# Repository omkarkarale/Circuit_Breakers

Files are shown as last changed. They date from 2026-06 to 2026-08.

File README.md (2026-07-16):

<h1 align="center">⚡ Circuit Breakers</h1>
<h3 align="center">MakerMania 2026 — Innovation Project Workbook</h3>

<p align="center">
  
  
  
</p>

<div align="center">

### 🛠️ Technologies Used





[]()

</div>

<p align="center">
  <strong>Program Duration:</strong> 1 June 2026 – 4 July 2026 &nbsp;·&nbsp;
  <strong>Location:</strong> MBF Tinkerers' Lab 007 &nbsp;·&nbsp;
  <strong>Team Size:</strong> 3 Students
</p>

<p align="center">
  <em>Identify a real-world problem and develop an innovative, patentable, and implementable solution.</em>
</p>

<p align="center">
  <a href="https://youtu.be/VeL1t_9wYrM?si=e5plWxUvcQX88zFm"><strong>📺 Advertisement Video</strong></a>
  &nbsp;&nbsp;|&nbsp;&nbsp;
  <a href="https://canva.link/8ibtr7vefrchxkn"><strong>📊 SCAMPER Presentation</strong></a>
</p>

---

# 1. Team Identity

## 1.1 Team Name and Photo

Team Name: Circuit Breakers

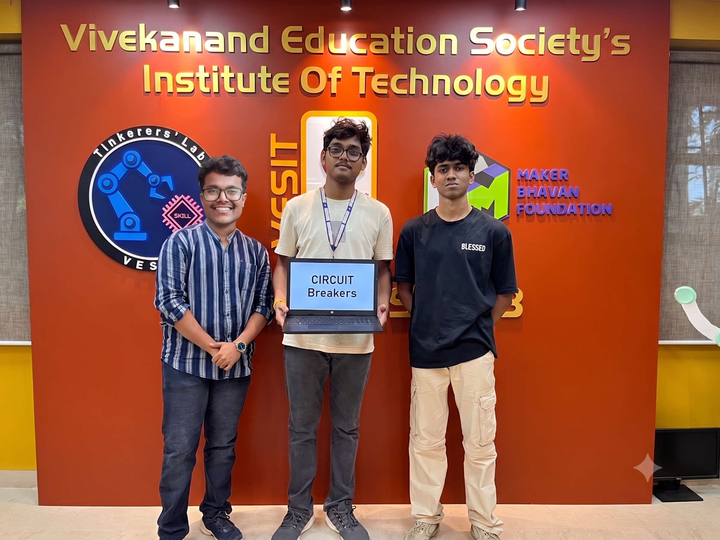
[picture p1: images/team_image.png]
<br>
---

## 1.2 Team Members

| Name | Role | Skills |
| ---- | ---- | --- |
| Rajnarayan Hazra | Hardware & Testing Lead | Arduino Mega programming, serial communication, documentation, electronics assembly |
| Omkar Karale | Software & IoT Lead | ESP8266 programming, app integration, 3D CAD |
| Ekansh Bansode | Mechanical Lead | 3D printing |

---

# 2. Problem Discovery

## 2.1 Observation Area

Where did you conduct your observations?

* Hostel
* Canteen
* Workshop
* **Hospital** (selected)
* Public Transport
* **Home** (selected)
* **Other** — Elderly care and caregiver support (selected)

---

## 2.2 AEIOU Observation Sheet

### Activities

What are users doing?

Users need to take different medicines at fixed times throughout the day (Medicine Scheduling), identify the correct medicine compartment and dosage (Dose Identification via LCD and voice guidance), and retrieve the correct medicine as the device rotates the compartment housing into position using the 28BYJ-48 stepper + ULN2003 (Medicine Retrieval).

### Environment

What conditions affect them?

The device is intended for homes, bedside tables, clinics, and elderly care spaces. Users may face forgetfulness, low vision, difficulty reading labels, or confusion when multiple medicines look similar.

### Interactions

Who or what are they interacting with?

The user interacts with the LCD display, voice announcements, the rotating medicine compartments, and the IR sensor. The companion app connects to the device over Wi-Fi through the ESP8266, which relays commands to the Arduino Mega over a serial connection; the Mega drives the hardware (motor, display, audio, sensor) while the ESP8266 handles logging and storage. Caregivers can use this app connectivity for schedule setup and notifications.

### Objects

What tools or products are used?

ESP8266 DevKit, DS3231 RTC, 16x2 LCD, 28BYJ-48 stepper motor + ULN2003 driver, DFPlayer Mini + speaker, IR sensor, Arduino Mega, and a custom 3D-printed (PLA) medicine compartment housing.

### Users

Who are the primary users?

The primary users are elderly patients and people with complex medication schedules. Secondary users include caregivers, family members, and healthcare workers.

---

## 2.3 Observation Log

| Observation | Evidence | Pain Point |
| --- | --- | --- |
| Elderly users may forget medicine timings. | Daily medicine routines often depend on alarms, handwritten notes, or caregiver reminders. | Missed doses reduce treatment effectiveness. |
| Multiple medicines can create confusion. | Similar tablets or unclear compartments make selection difficult. | Users may take the wrong medicine or dosage. |
| Caregivers cannot always monitor intake in person. | Family members may be away during scheduled medicine times. | No reliable confirmation that medicine was accessed. |

---

# 3. User Research

## 3.1 Interview Summary

Number of users interviewed: **Elderly users, family members, and caregivers**

Methods used: Informal interviews, observation, and discussion of daily medicine routines.

## 3.2 Key Quotes

1. "A normal alarm tells the time, but it does not tell which medicine to take."

2. "It is difficult to remember tablets when there are many doses in one day."

3. "Caregivers need to know whether the medicine was actually accessed."

---

## 3.3 User Persona

### Name

Mr. Das

### Age

68 years

### Occupation

Retired

### Goals

Take medicines on time, avoid confusion, and remain independent.

### Frustrations

Forgetting doses, reading small labels, and depending on family members.

### Needs

Clear reminders, voice guidance, visible compartment indication, and simple operation.

---

# 4. Problem Framing

## Problem Statement

User **elderly patients and people with complex medication schedules** needs a way to **identify and take the correct medicine at the correct time** because **missed doses, wrong doses, and dependency on caregivers can affect health and independence**.

---

## How Might We Questions

1. How might we help elderly users identify the correct medicine without confusion?

2. How might we make medicine reminders clearer than a normal phone alarm?

3. How might we help caregivers receive confirmation of medicine access?

---

## Opportunity Ranking

| Criteria | Score |
| --- | ----- |
| Severity | 5 — Incorrect or missed medication can directly affect health. |
| Frequency | 5 — Medicines are often taken daily and multiple times per day. |
| Feasibility | 4 — Uses affordable and commonly available components. |
| Novelty | 4 — Combines a custom 3D-printed compartment design, voice guidance, motorized positioning, and IoT. |
| Market Potential | 4 — Useful for elderly care, home healthcare, and caregiver support. |
| Total | 22/25 |

---

# 5. Solution Ideation

## Brainstormed Ideas

| Idea | Advantages | Challenges |
| ---- | --- | --- |
| Mobile medicine reminder app | Easy to update schedules and send notifications | Does not physically guide medicine selection |
| Alarm-based pill box | Simple and low cost | User still needs to open the correct compartment |
| Smart rotating medicine organizer | Provides reminder, sorting, voice guidance, visual indication, and access detection | Requires motor calibration and reliable mechanical alignment |

---

## Selected Concept

Why was this concept chosen?

The selected concept is a Smart Medicine Sorting and Reminder Device built using a custom 3D-printed (PLA) compartment housing, designed by taking inspiration from existing web references rather than reusing an off-the-shelf part. It solves both the reminder and medicine identification problems by alerting the user, rotating to the correct compartment, providing voice instructions, and detecting compartment access.

---

# 6. System Design

## High-Level Description

Explain your solution.

The Smart Medicine Sorting and Reminder Device is an IoT-enabled healthcare solution that helps elderly patients and individuals with complex medication schedules take medicines on time and correctly. Medicines are preloaded into weekly compartments inside a custom 3D-printed (PLA) housing. The system runs on two controllers working together: the **Arduino Mega** drives all hardware — reading the DS3231 RTC, updating the 16x2 LCD, playing voice reminders through the DFPlayer Mini and speaker, rotating the 28BYJ-48 stepper motors to the correct compartment, and reading the IR sensor — while the **ESP8266** connects over Wi-Fi to the companion app, sends commands to the Mega over a serial link, and handles log storage. At the correct time, the device announces the reminder, shows medicine information on the LCD, and rotates to the correct slot; the IR sensor detects access and supports logging or caregiver notification. The hardware and software are fully working; current effort is focused on improving the physical enclosure.

---

## Block Diagram

```mermaid
flowchart LR
    A["📱 Mobile App<br/>(Wi-Fi)"]
    B["📡 ESP8266<br/>Wi-Fi + Logging + Storage"]
    C["🔌 Serial (UART)"]
    D["🖥️ Arduino Mega"]

    E["⏰ RTC"]
    F["🖥️ LCD"]
    G["🔊 DFPlayer Mini<br/>+ Speaker"]
    H["⚙️ Stepper Motors"]
    I["📷 IR Sensor"]

    A -->|HTTP API| B
    B -->|UART Serial| C
    C --> D

    D --> E
    D --> F
    D --> G
    D --> H
    D --> I
```
---

## Inputs

List sensors, user inputs, data sources.

* Companion app (via ESP8266 Wi-Fi) — configure schedules and caregiver setup
* DS3231 RTC — accurate real-time scheduling
* IR sensor — detects compartment access or medicine retrieval
* ESP8266 → Arduino Mega (Serial) — relays commands from the app/ESP8266 to the hardware controller

---

## Outputs

List displays, actuators, software outputs.

* 16x2 LCD — shows current time, status, and medication information
* DFPlayer Mini + speaker — voice reminders and dosage instructions
* 28BYJ-48 stepper motors — rotate the compartment housing to the correct slot

---

# 7. Technical Planning

## Electronics

| Component | Purpose |
| --- | --- |
| Arduino Mega | Main hardware controller — drives motors, display, audio, and sensor, and receives commands over serial |
| ESP8266 DevKit | Wi-Fi connectivity, app communication, and log storage |
| DS3231 RTC Module | Accurate real-time clock for medicine schedules |
| 16x2 LCD | Displays time, status, and medicine information |
| 28BYJ-48 Stepper Motor (x3) | Rotates the medicine compartments |
| ULN2003 Motor Driver (x3) | Drives the stepper motors |
| DFPlayer Mini + Speaker | Plays voice reminders and dosage instructions |
| IR Sensor | Detects access or retrieval |
| 12V Adapter / 18650 Battery | Power supply |

---

## Software

| Tool | Purpose |
| ---- | --- |
| Arduino IDE | Firmware development for both ESP8266 and Arduino Mega |
| ESP8266 Arduino Core | ESP8266 programming and wireless features |
| RTC library | DS3231 timekeeping and schedule checking (Mega side) |
| LCD display library | Displaying time, status, and medicine details (Mega side) |
| Stepper motor library | Controlling compartment rotation (Mega side) |
| DFPlayer Mini library | Playing audio reminder files (Mega side) |
| Wi-Fi libraries | Mobile app connectivity and caregiver notifications (ESP8266 side) |
| Serial communication protocol | Passes commands from the ESP8266 to the Arduino Mega |

---

## Mechanical / CAD

Describe fabricated components.

The compartment housing is a custom CAD design, 3D-printed in PLA and built from scratch by taking inspiration from web references — it is not a repurposed 3D-printer filament spool. Multiple sizes and surface finishes were tried across iterations. The housing holds the medicine compartments, motor mounts, and electronics enclosure.

<p align="center">
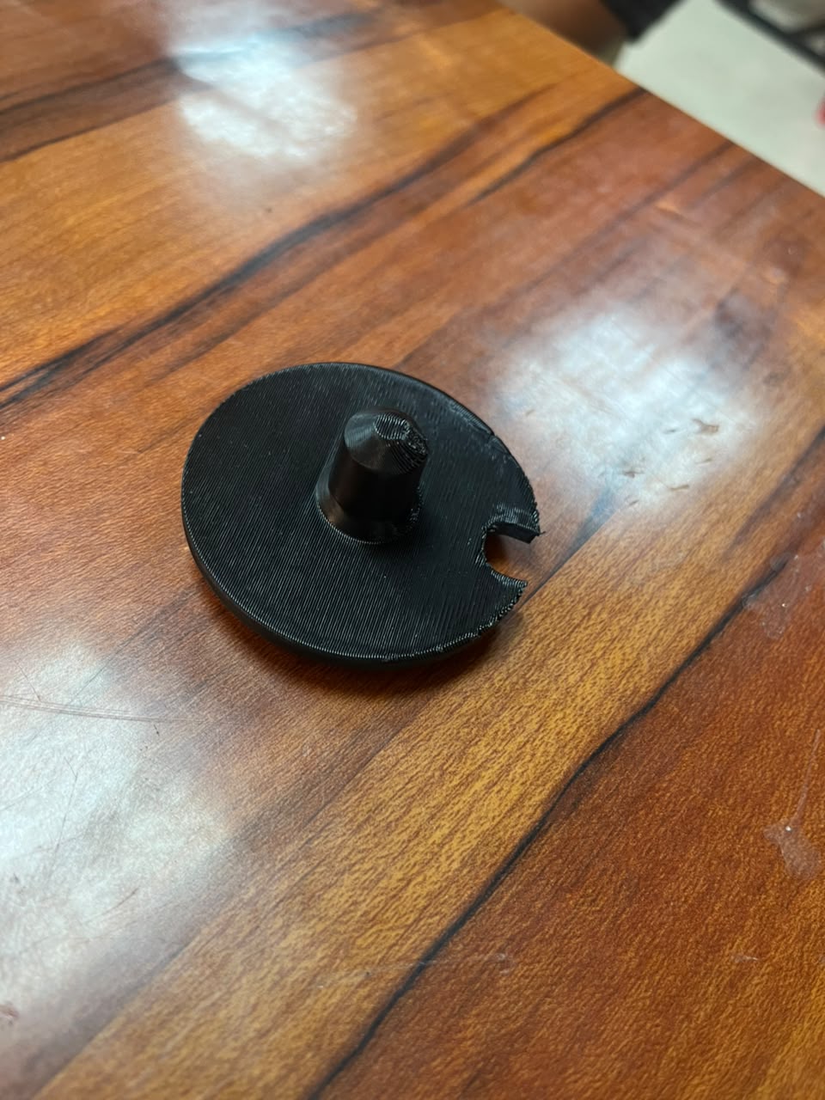
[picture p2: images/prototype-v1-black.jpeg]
Early compartment lid prototype (PLA, black)
  <br>
  <em>Early PLA compartment lid prototype — printed in black filament</em>
</p>

<p align="center">
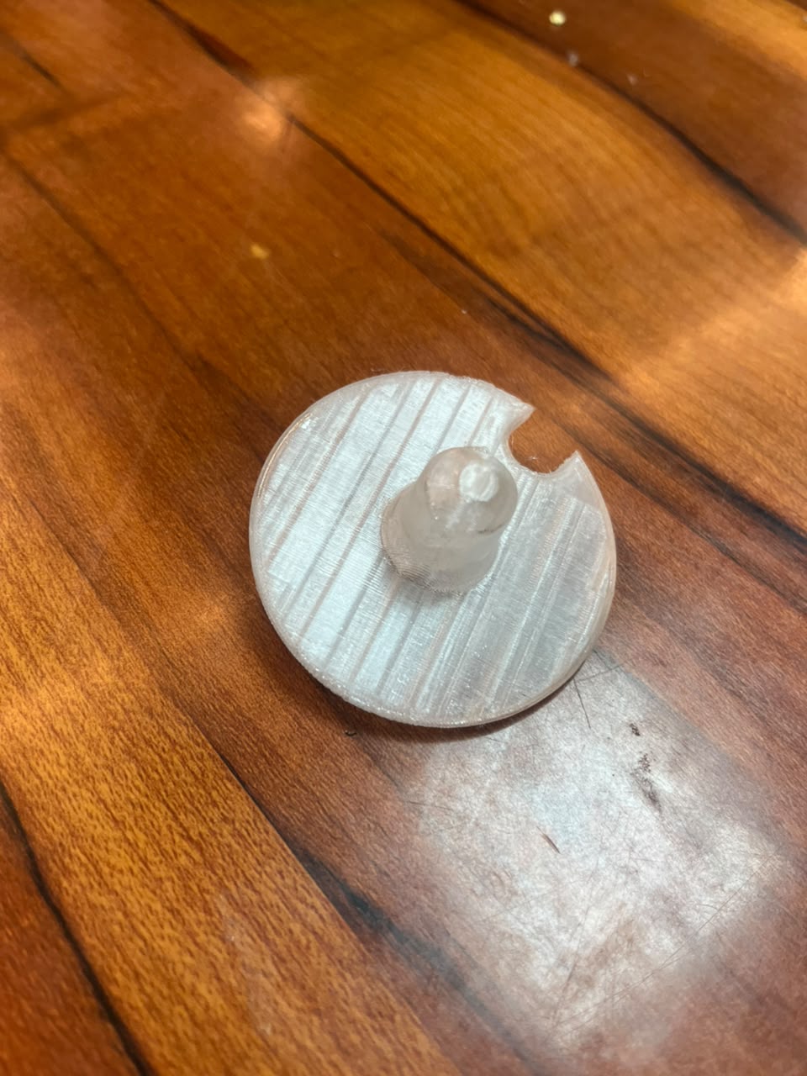
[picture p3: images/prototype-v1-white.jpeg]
Early compartment lid prototype (PLA, white)
  <br>
  <em>Same lid design reprinted in white/translucent PLA to test a different finish</em>
</p>

---

# 8. Prototype Development

## Version 1

Description: Basic circular medicine organizer concept, custom-designed and 3D-printed in PLA (not a recycled filament spool) with marked compartments, inspired by references found online.

Lessons Learned: Compartments must be clearly visible, easy to access, and aligned with the rotation mechanism.

---

## Version 2

Description: Arduino Mega + ESP8266 based prototype with RTC scheduling, LCD display, stepper-based rotation, and serial communication between the two controllers.

Lessons Learned: Accurate timing, motor calibration, and simple feedback are essential for reliable use.

<p align="center">
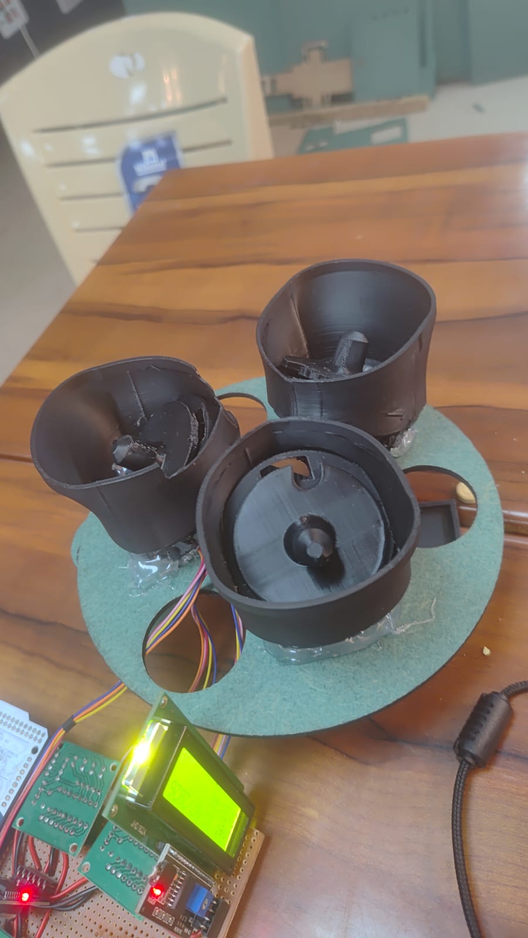
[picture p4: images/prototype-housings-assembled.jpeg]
Three compartment housings assembled on the base
  <br>
  <em>Three 3D-printed compartment housings assembled onto the base with the stepper motors and wiring routed through</em>
</p>

---

## Final Prototype

Description: IoT-enabled medicine sorting and reminder device with voice guidance, motorized compartment positioning, LCD status display, and IR access detection. Hardware (Arduino Mega) and software (ESP8266 + companion app) are fully working and communicate correctly over serial and Wi-Fi.

Current Status: The electronics and firmware are functioning as intended, but the 3D-printed enclosure is not yet finalized. Several iterations were tried — different housing sizes and surface/scrubbing treatments — but the model still has fit, alignment, and durability issues and is not fully user-friendly. Following review feedback from the presentation, further redesign of the physical model is in progress.

<p align="center">
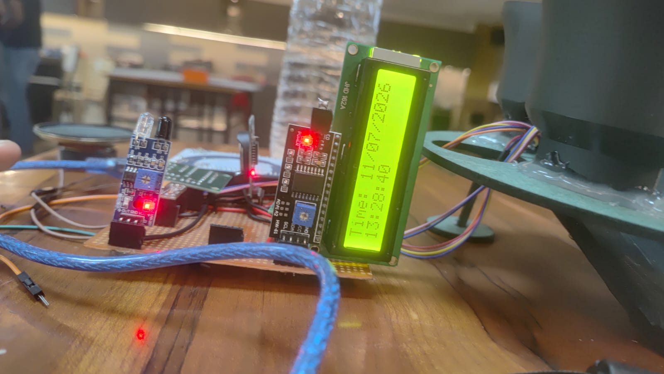
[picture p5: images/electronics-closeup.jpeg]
Close-up of RTC, LCD, and IR sensor wiring
  <br>
  <em>Close-up of the DS3231 RTC, 16x2 LCD, and IR sensor wired on the breadboard</em>
</p>

<p align="center">
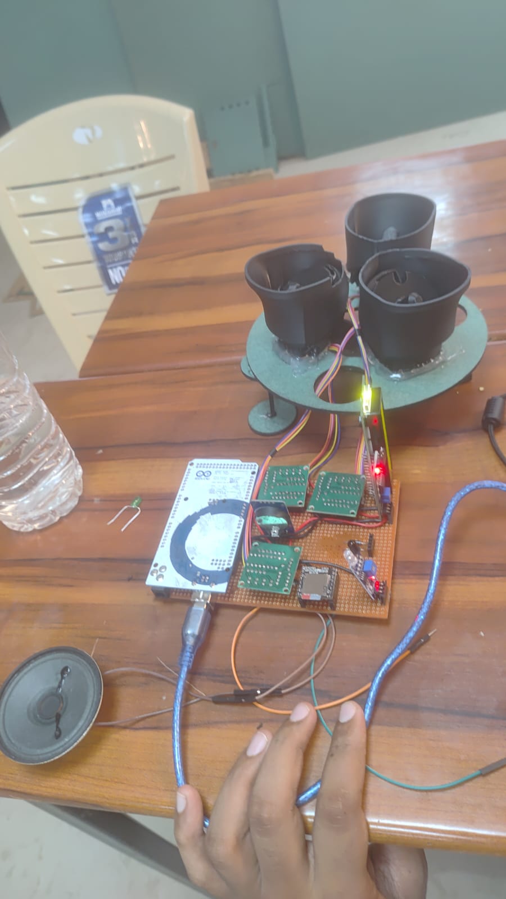
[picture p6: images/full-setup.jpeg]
Full working setup with Arduino Mega, breadboards, and compartment housings
  <br>
  <em>Full working setup — Arduino Mega, breadboard modules, speaker, and compartment housings connected together</em>
</p>

---

# 9. Testing & Validation

## Testing Plan

| Test | Success Criteria |
| ---- | --- |
| RTC schedule reminder | Reminder activates at the programmed time |
| Motor positioning | Compartment housing rotates to the correct slot |
| Voice and sensor feedback | Correct audio plays and access is detected |

---

## User Feedback

| User | Feedback | Action Taken |
| ---- | --- | --- |
| Elderly user | Voice reminders are easier to understand than a simple chime. | Added DFPlayer Mini and speaker for audio guidance. |
| Caregiver | Clear compartment guidance is important to avoid confusion. | Used LCD messaging and mechanical positioning for guidance. |
| Presentation reviewers | The current 3D-printed model is not user-friendly and needs a better enclosure design, even though the hardware and software work correctly. | Redesign of the physical model is underway after trying multiple sizes and surface treatments. |

---

# 10. Innovation Assessment

## Existing Solutions

List competing products.

| Product / Patent | Strengths | Weaknesses |
| --- | --- | --- |
| Basic pill organizer | Low cost and simple | No automatic reminder, voice guidance, or access detection |
| Phone alarm reminder | Easy to set and portable | Does not identify the correct medicine or compartment |
| Smart pill dispenser | Automated and connected | Often costly |

---

## What Makes This Different?

This project combines a custom-designed, 3D-printed PLA compartment housing, motorized compartment positioning, voice guidance, and IoT connectivity split across an ESP8266 (app/Wi-Fi/logging) and an Arduino Mega (hardware control) working together over serial. It supports elderly users and caregivers with a fully working hardware and software stack, while the physical enclosure continues to be refined for better usability.

---

## Innovation Score

| Parameter | Score |
| --- | ----- |
| Novelty | 4 — Uses a custom 3D-printed compartment housing, designed from web references, as the main circular medicine organizer. |
| Technical Depth | 4 — Integrates ESP8266, RTC, motor control, audio, display, sensor, and wireless features. |
| Feasibility | 4 — Uses low-cost and easily available components. |
| Impact | 5 — Helps reduce missed doses and incorrect medicine intake. |
| Scalability | 4 — Can be expanded with app support, cloud logs, and caregiver alerts. |

---

# 11. Intellectual Property

## Prior Art Search

Patents / Products Found:

| Reference | Relevance | Differentiation |
| --- | --- | --- |
| Traditional pill boxes | Organize medicines by day and time | No motorized slot positioning, voice guidance, or IoT logging |
| Electronic reminder pill boxes | Provide alarm-based reminders | Limited support for identifying the correct compartment |
| Smart pill dispensers | Automate medicine dispensing | Higher cost and not built around a custom low-cost, dual-controller (ESP8266 + Arduino Mega) design |

---

## Novel Features

1. Custom 3D-printed (PLA) circular smart medicine organizer, designed from web references.

2. Motorized compartment positioning combined with voice guidance.

3. Dual-controller architecture — ESP8266 for app connectivity and log storage, Arduino Mega for hardware control — with low-cost access detection and caregiver connectivity.

---

## Provisional Patent Draft

### Title

Smart Medicine Sorting and Reminder Device Using a Custom 3D-Printed Compartment Mechanism

### Abstract

An IoT-enabled medicine organizer built around a custom-designed, 3D-printed PLA circular storage mechanism. The system provides scheduled reminders, motorized compartment positioning, voice guidance, and access detection for medicine retrieval, coordinated through an ESP8266 (connectivity and logging) and an Arduino Mega (hardware control).

### Problem

Elderly patients and users with complex medicine schedules often miss doses or take incorrect medicines due to confusion, forgetfulness, or lack of caregiver support.

### Solution

A low-cost smart organizer that stores weekly medicine doses, alerts the user at scheduled times, rotates to the correct compartment, announces instructions, and detects access.

### Claims

Custom 3D-printed compartment design, scheduled motorized positioning, dual-controller (ESP8266 + Arduino Mega) architecture, and caregiver notification support through ESP8266 connectivity.

---

# 12. Business & Deployment

## Target Users

Elderly patients, people with chronic illnesses, caregivers, families, clinics, and home healthcare providers.

## Estimated Cost

Low-cost prototype using an ESP8266, Arduino Mega, RTC, LCD, motor, audio module, IR sensor, and a custom 3D-printed PLA body.

## Market Opportunity

Growing demand for elderly care, home healthcare, medication adherence tools, and affordable assistive devices.

## Sustainability Considerations

Uses PLA, a biodegradable/plant-derived filament, for the enclosure; enclosure design is being iterated to reduce material waste in future print runs.

---

# 13. Final Demonstration

## Prototype Images

<p align="center">
  Demo 1 - Full working setup
  Demo 2 - Assembled compartment housings
</p>

---

## Demonstration Video Link

---

## GitHub Repository

https://github.com/mbftinkererslab-vesit/MakerMania_2026-

---

## Presentation Link

https://github.com/omkarkarale/MakerMania-2026-CircuitBreakers/blob/main/REPORT.pdf

---

# 14. Reflection

## What Worked Well?

The hardware and software stack works correctly end-to-end — the app, ESP8266, and Arduino Mega communicate reliably, and scheduling, voice guidance, and access detection all function as intended.

## What Failed?

The physical 3D-printed enclosure is not yet reliable or user-friendly. Multiple iterations were tried (different sizes, surface scrubbing/finishing), but alignment, fit, and durability issues remain, as noted in presentation reviews.

## Key Learnings

Healthcare devices must be reliable, simple to use, and clear through both audio and visual feedback — and getting the electronics and firmware working is not enough if the physical enclosure isn't equally refined and user-friendly.

## Next Steps

* Patent Filing
* Startup Exploration
* Product Development
* Research Publication
* Competition Submission

---

# 15. Final Deliverables Checklist

* Problem Discovery Complete ✅
* User Interviews Complete ⬜
* Persona Created ✅
* Problem Statement Finalized ✅
* System Design Complete ✅
* Prototype Demonstrated ⬜
* Testing Completed ⬜
* Patent Draft Prepared ✅
* Presentation Submitted ⬜
* GitHub Repository Updated ✅

---

# MAKERMANIA FINAL PITCH

Each team will present:

1. Problem: missed and incorrect medicine intake
2. User Research: elderly users and caregivers need clearer reminders
3. Insights: voice, visual, and physical positioning reduce confusion
4. Solution: smart rotating medicine organizer using a custom 3D-printed compartment housing
5. Prototype Demo: reminder, voice instruction, and motor rotation
6. Innovation & Patentability: low-cost, dual-controller IoT device with a custom-designed enclosure
7. Future Roadmap: refined and more user-friendly enclosure, app connectivity, caregiver alerts, and logging

Presentation Time: 5 Minutes

Q&A: 3 Minutes

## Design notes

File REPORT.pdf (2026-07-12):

## Team – Circuit Breakers

Sr. No. | Team Member | Department
1. | Rajnarayan Hazra | ECS
2. | Omkar Karale | ECS
3. | Ekansh Bansode | ECS

## I. Problem Statement & Observation:

Patients, especially elderly individuals and those managing multiple medications, require a reliable, affordable, and automated medicine dispensing system because manually remembering medication schedules often leads to missed or incorrect doses. Existing solutions are expensive, bulky, or lack personalized scheduling, making them impractical for everyday home use.
Major Observations -
- Patients frequently forgot to take medicines at the prescribed time.
- Caregivers had to manually remind patients multiple times a day.
- Missing or incorrect medication doses affected treatment adherence.
- Managing multiple medicines with different schedules caused confusion.
- Existing automated medicine dispensers were expensive and inaccessible for many users.
- Conventional pill organizers provided storage but did not offer reminders or automatic dispensing.
- Patients often forgot whether they had already taken a scheduled dose.
- Family members could not easily monitor whether medicines were taken on time.
- Elderly users preferred a simple system with audio and visual reminders instead of mobile app notifications.
- A low-cost, automated medicine dispenser with scheduled dispensing and confirmation of medicine retrieval would significantly improve medication adherence and patient independence.

## II. Solution & Design:

The proposed Smart Medicine Dispenser is a compact, low-cost automated medication management system designed to assist patients in taking their medicines on time. The system stores up to three different medicines, dispenses them according to a predefined schedule, and provides both audio and visual reminders to ensure timely medication intake. Unlike many commercial automated dispensers, the proposed solution focuses on affordability, ease of use, and reliability, making it suitable for home use, especially for elderly patients and individuals managing multiple medications.

The operation follows these steps:

### 1. A medicine schedule is registered through the ESP8266 and transmitted to the

Arduino Mega via Serial3.

### 2. The Arduino Mega stores the medicine name, dosage schedule, dispensing times, and

treatment duration.

3. The DS3231 Real-Time Clock (RTC) continuously tracks the current date and time.

### 4. At the scheduled time, the Arduino Mega compares the current time with the stored

medication schedule.

### 5. The corresponding stepper motor rotates to dispense the prescribed medicine from the

appropriate compartment.

### 6. The DFPlayer Mini plays an audio reminder while the LCD displays the medicine

information and dispensing status.
7. The IR sensor detects whether the medicine has been collected by the patient.

### 8. Once the medicine is collected, the system records the dose as completed and waits

for the next scheduled dispensing time.

### 9. The process repeats automatically until the prescribed treatment duration is

completed, after which the medicine schedule is removed from the system.

The project began by studying the challenges faced by patients and caregivers in maintaining medication schedules through observations and discussions. The team identified the need for an affordable, automated medicine dispenser capable of handling multiple medicines with minimal user intervention. Suitable hardware components were selected, including an Arduino Mega, ESP32, RTC module, stepper motors, IR sensor, DFPlayer Mini, and LCD display. The hardware and software were then integrated, and the complete prototype was developed and tested to validate accurate scheduling, reliable dispensing, and user-friendly operation.

## III. Components & Technical Planning:

Sr. No. | Component | Purpose
1 | Arduino Mega 2560 | Acts as the main controller, stores medicine schedules, processes dispensing logic, controls the stepper motors, LCD, RTC, DFPlayer Mini, and communicates with the ESP8266.
2 | ESP8266 NodeMCU | Provides Wi-Fi connectivity, hosts the web interface for medicine registration, and transmits medicine schedules to the Arduino Mega through Serial3 communication.
3 | DS3231 RTC Module | Maintains accurate date and time, allowing medicines to be dispensed precisely according to the prescribed schedule, even after power interruptions.
4 | 28BYJ-48 Stepper Motors (×3) | Rotate the medicine compartments to dispense the correct medicine from each of the three slots at the scheduled time.
5 | ULN2003 Stepper Driver Modules (×3) | Drive the 28BYJ-48 stepper motors by providing the required current and control interface from the Arduino Mega.
6 | 16×2 I2C LCD Display | Displays the current time, medicine name, dispensing status, and system notifications for the user.

7 | DFPlayer Mini | Plays pre-recorded voice reminders and audio notifications to alert the patient when it is time to take the prescribed medicine.
8 | Speaker | Outputs the voice reminders and alert tones from the DFPlayer Mini.
9 | IR Sensor Module | Detects whether the dispensed medicine has been collected by the patient, allowing the system to confirm successful medicine retrieval.
10 | 5V DC Power Supply / Adapter | Provides a stable power supply to the Arduino Mega, ESP8266, and all connected modules.

## IV. Challenges & Solutions:

The project faced several challenges during both the hardware and software development phases. Mechanically, designing a reliable 3D-printed medicine dispensing mechanism required multiple iterations to achieve smooth rotation, accurate alignment of the medicine compartments, and consistent dispensing without pills getting stuck or jammed. Adjustments to the compartment dimensions, clearances, and stepper motor coupling were necessary to improve reliability and ensure proper operation.

On the electronics and software side, challenges included maintaining accurate medicine dispensing schedules, ensuring reliable communication between the ESP8266 and Arduino Mega, synchronizing the RTC with the dispensing logic, detecting successful medicine retrieval using the IR sensor, and integrating multiple hardware modules into a single system. These challenges were addressed by using the DS3231 RTC for precise timekeeping, implementing robust serial communication between the ESP8266 and Arduino Mega, refining the 3D-printed design through repeated prototyping, and adopting a modular software architecture for easier integration and maintenance. Careful component selection, extensive testing, and effective teamwork helped overcome budget, mechanical, and development time constraints, resulting in a reliable, affordable, and user-friendly automated medici

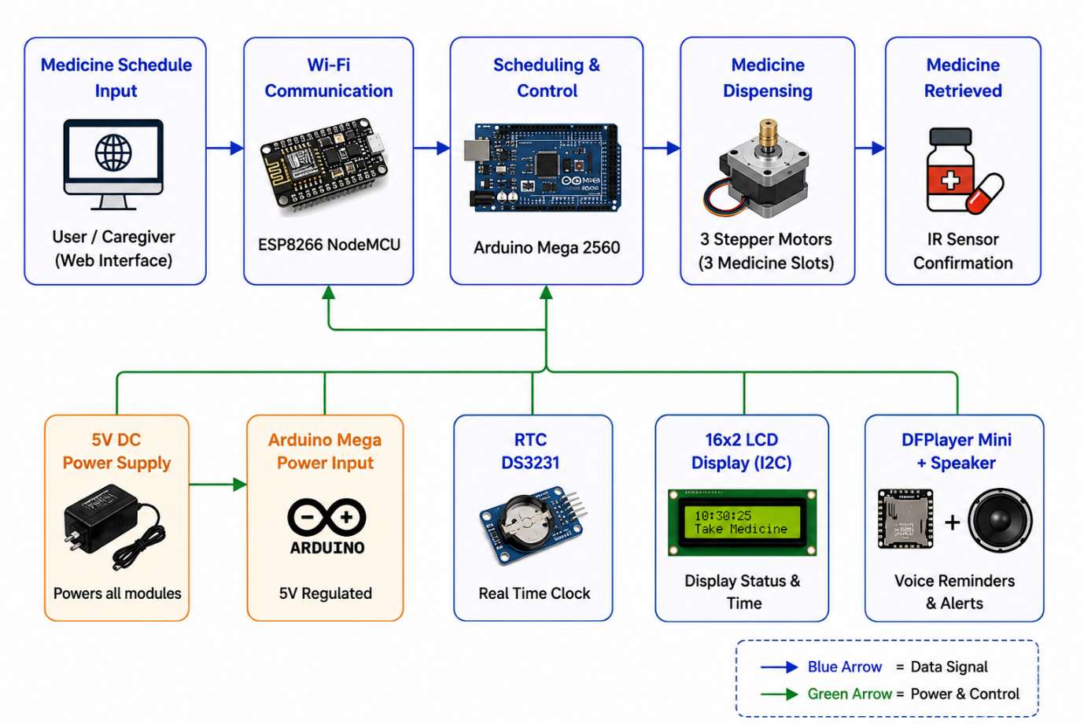
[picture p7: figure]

ne dispenser.

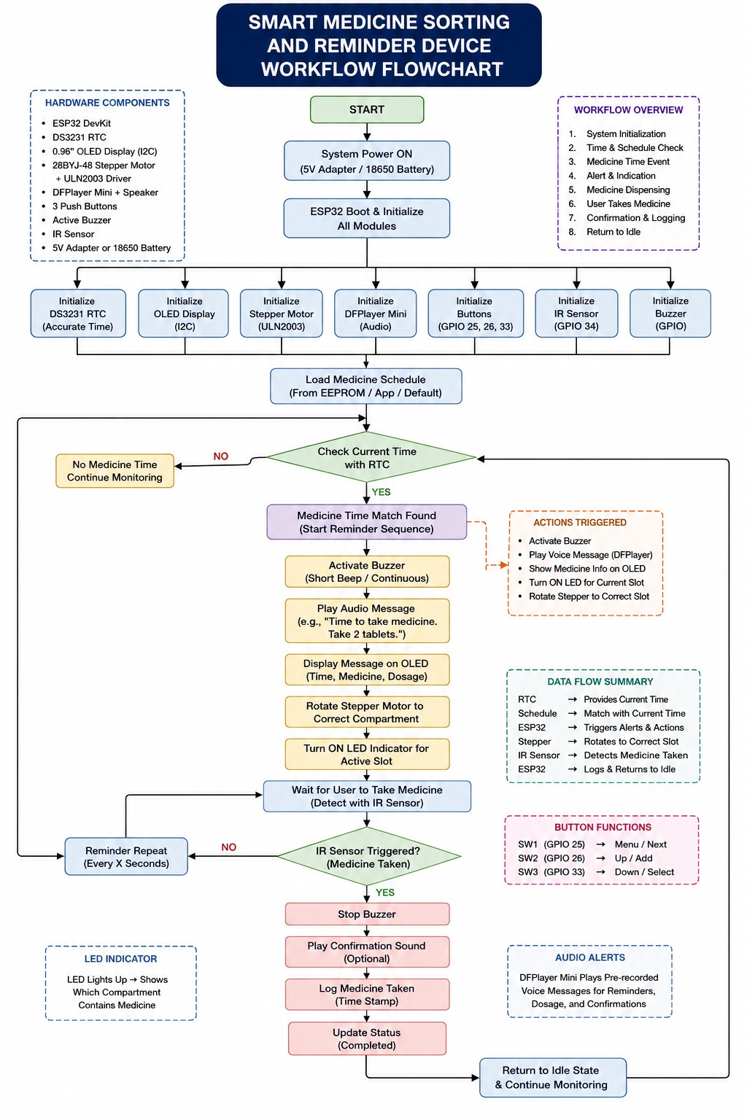
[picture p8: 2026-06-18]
ELECTRONICS/flowchart.jpeg

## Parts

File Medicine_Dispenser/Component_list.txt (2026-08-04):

ESP8266 DevKit
Arduino Mega
DS3231 RTC
16x2 LCD
28BYJ-48 stepper + ULN2003
DFPlayer Mini + speaker
IR sensor
5V adapter or 18650 battery

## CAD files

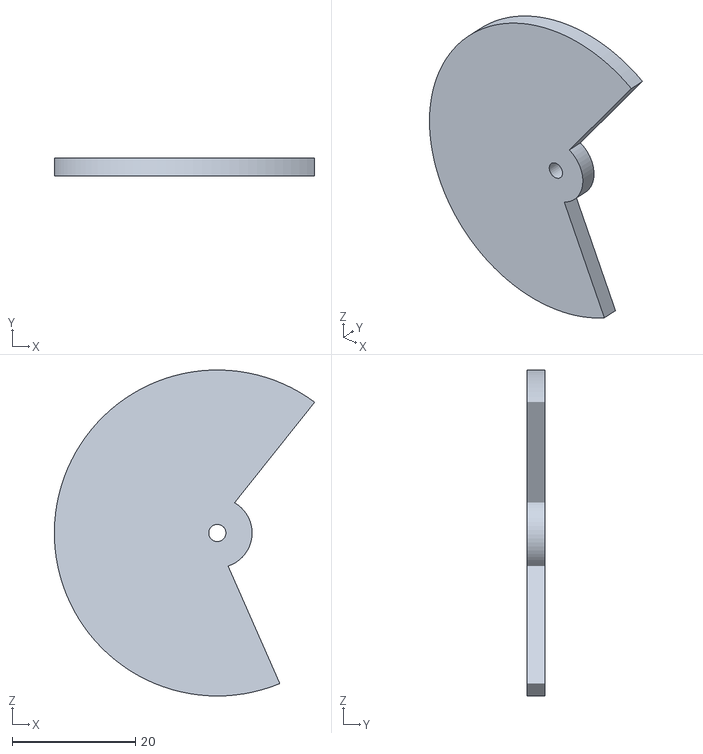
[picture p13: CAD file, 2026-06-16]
cad/USELESS/cap cap.stl
42.3 x 3.00 x 53.0

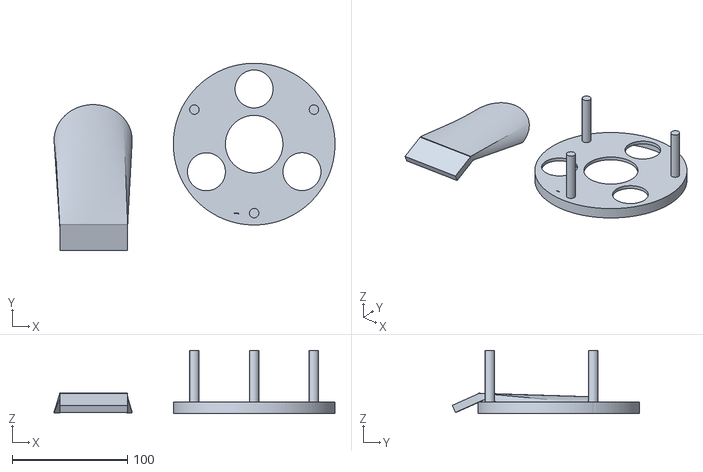
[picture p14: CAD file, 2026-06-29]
Medicine_Dispenser/MODELS/Dispenser base.stl
244.3 x 162.9 x 55.0

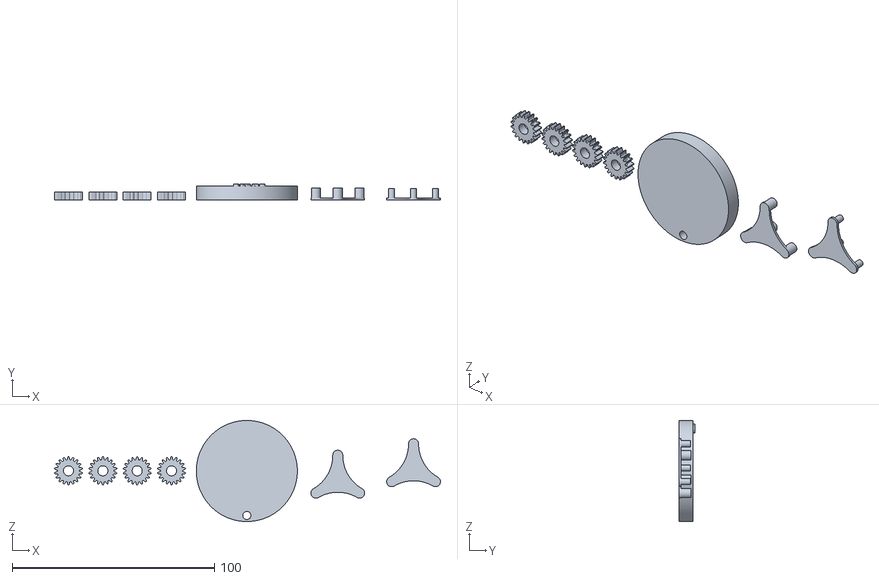
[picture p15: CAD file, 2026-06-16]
Training Material/Fusion 360/Omkar Keychain - Planetary System Gear.stl
191.0 x 8.00 x 50.0

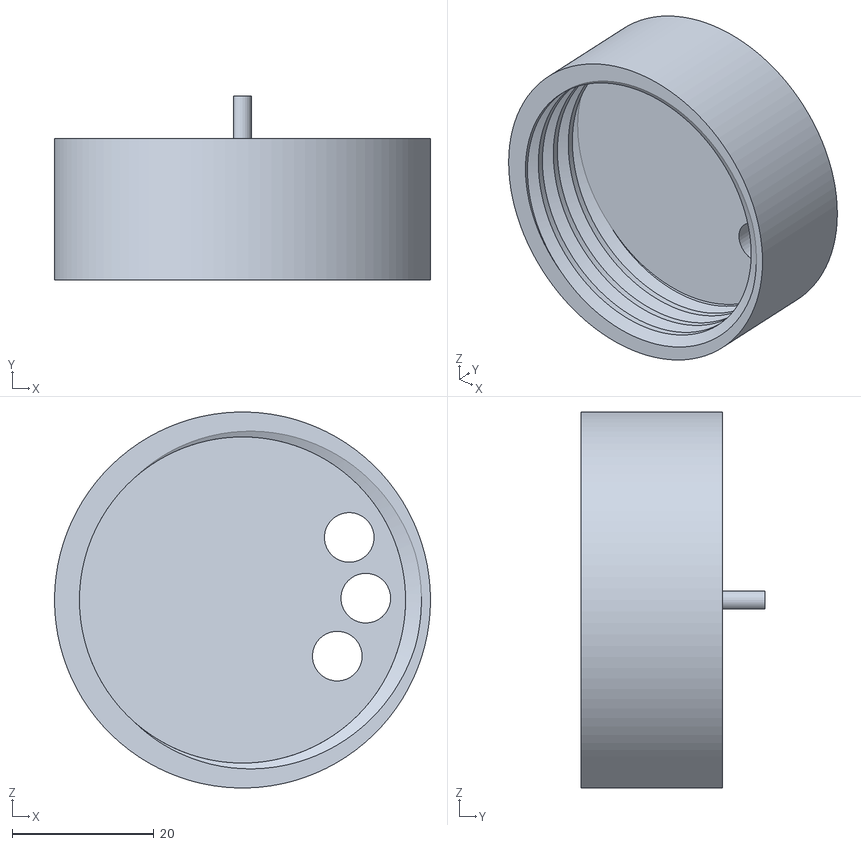
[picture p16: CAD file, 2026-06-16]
cad/USELESS/bottle cap.stl
53.0 x 26.0 x 53.0

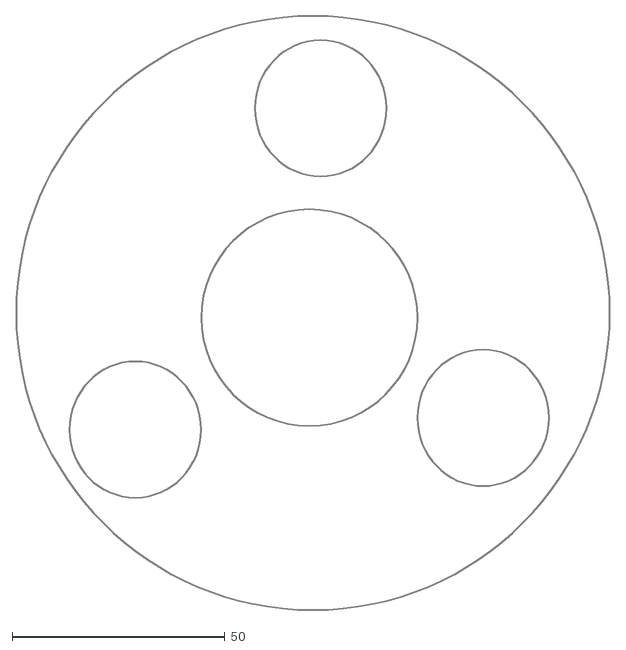
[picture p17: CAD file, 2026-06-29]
Medicine_Dispenser/MODELS/base.dxf
139.4 x 139.4

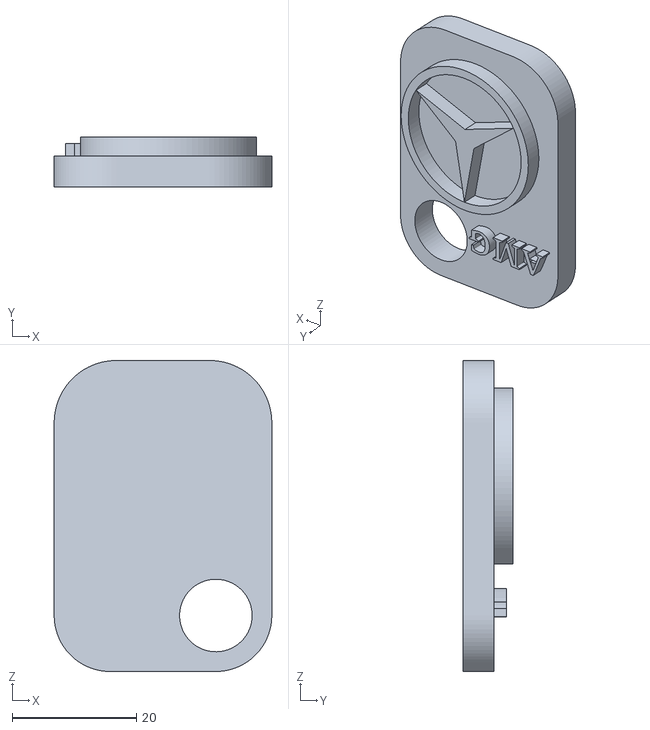
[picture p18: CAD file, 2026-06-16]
Training Material/Fusion 360/Rajnarayan Keychain - AMG.stl
35.0 x 8.00 x 50.0

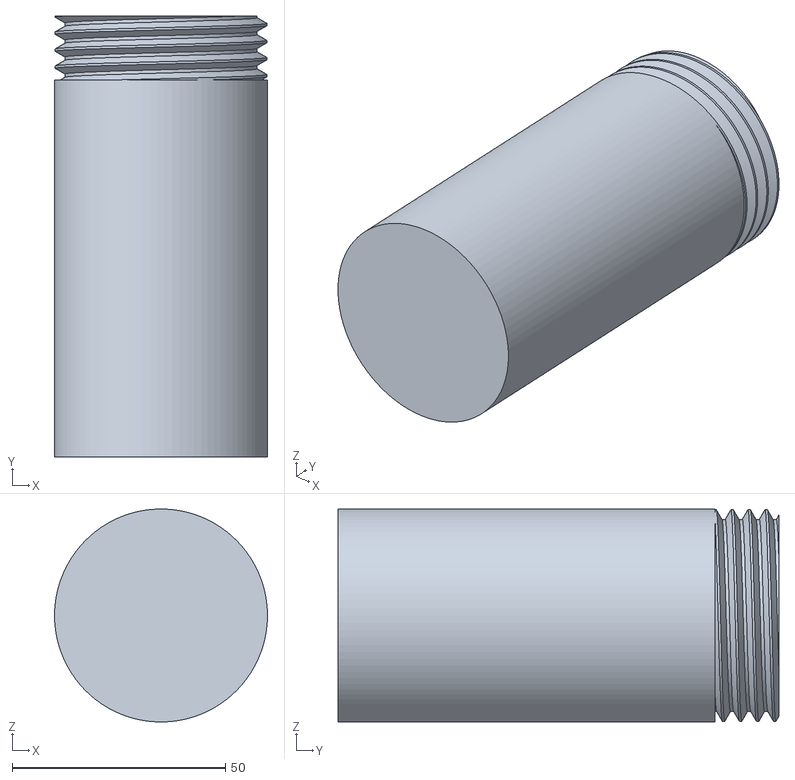
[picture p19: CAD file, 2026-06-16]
cad/USELESS/AIR BOTTLE.stl
50.0 x 103.5 x 50.0

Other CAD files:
cad/3D SPOOL.f3d

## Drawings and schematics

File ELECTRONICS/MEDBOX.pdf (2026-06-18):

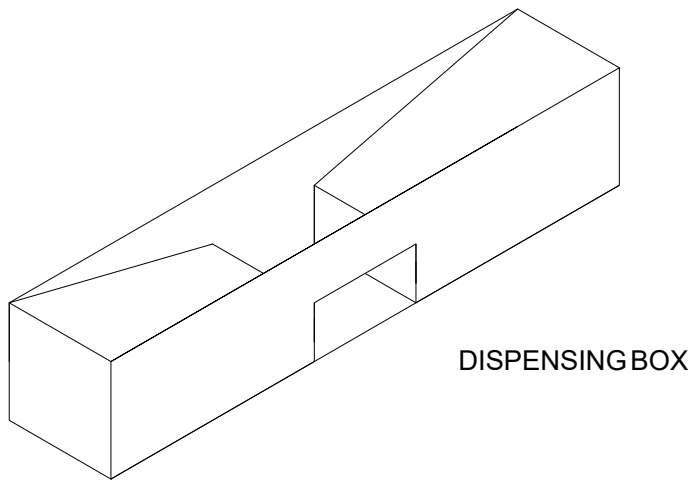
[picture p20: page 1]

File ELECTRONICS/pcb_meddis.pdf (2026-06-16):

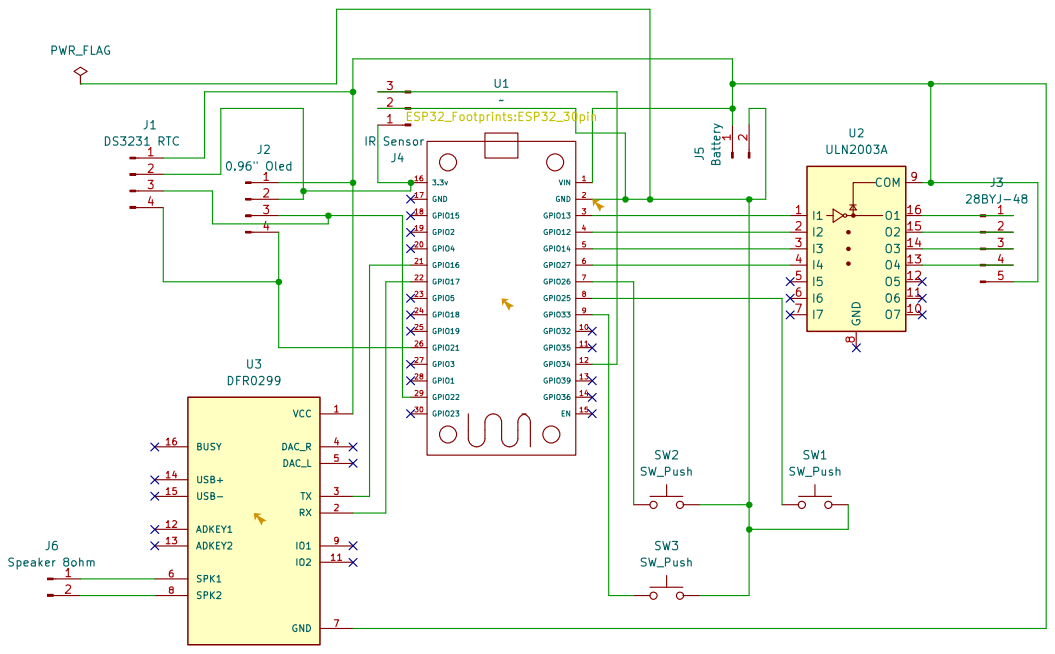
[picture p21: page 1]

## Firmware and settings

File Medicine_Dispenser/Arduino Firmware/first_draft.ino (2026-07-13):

// ============================================================================
// Medicine Dispenser
// ----------------------------------------------------------------------------
// A stepper-motor based automatic medicine dispenser.
// - Keeps time using an RTC (DS3231) and displays it on a 16x2 I2C LCD.
// - Stores up to 3 medicines (one per slot) with custom dosing schedules
//   (up to 5 doses/day, on chosen days of the week) in EEPROM so the
//   schedule survives power loss.
// - When a scheduled dose time is reached, it announces/dispenses the
//   medicine, plays an audio prompt (DFPlayer Mini MP3 module), and waits
//   for an IR sensor to detect that the medicine has been picked up.
// - Medicine schedules can be programmed/updated over Serial (e.g. from an
//   ESP8266 companion board or a PC) using a simple comma-separated protocol.
// ============================================================================

#include <Stepper.h>                  // Library to drive 28BYJ-48 stepper motors via ULN2003 driver
#include <DFRobotDFPlayerMini.h>      // Library for the DFPlayer Mini MP3 module (audio prompts)
#include <Wire.h>                     // I2C communication (used by LCD and RTC)
#include <LiquidCrystal_I2C.h>        // I2C-based 16x2 character LCD driver
#include <RTClib.h>                   // Real-Time Clock (DS3231) library
#include <EEPROM.h>                   // Non-volatile storage so medicine schedules persist across reboots
#include <ArduinoJson.h>              // Newline-delimited ESP8266 bridge protocol

#define IR 8                          // Digital pin connected to the IR "pill tray" sensor

unsigned long old_time;               // Last millis() timestamp the LCD time/date was refreshed
unsigned long timer;                  // (Unused elsewhere) general-purpose timer variable
int lastDispenseMinute = -1;          // Minute of the last dispense event, used to avoid re-triggering within the same minute
int lastDispenseHour = -1;            // Hour of the last dispense event, used to avoid re-triggering within the same minute
unsigned long lastReminder = 0;       // millis() timestamp of the last audio reminder played while waiting for pickup
const unsigned long reminderInterval = 5000;   // 5 seconds - how often to repeat the "take your medicine" reminder sound

String message;                       // Buffer holding the most recent line read from Serial (from ESP8266/PC)

// ESP8266 link: Mega Serial3 (RX3=15, TX3=14), 9600 baud, one JSON object per
// line. USB Serial remains available for local diagnostics only.
String espRxBuffer;

RTC_DS3231 rtc;                       // RTC object used to read the current date/time
// Common I2C addresses: 0x27 or 0x3F
LiquidCrystal_I2C lcd(0x27, 16, 2);   // LCD object: I2C address 0x27, 16 columns x 2 rows
DFRobotDFPlayerMini player;           // MP3 player object for audio prompts




// Stepper motor configuration for the three dispenser slots
const int stepsPerRevolution = 2048;  // 28BYJ-48 full revolution (steps needed for one full turn)
// IN1, IN3, IN2, IN4 pins on ULN2003
Stepper myStepper1(stepsPerRevolution, 24, 26, 25, 27);  // Stepper motor for slot 1
Stepper myStepper2(stepsPerRevolution, 44, 46, 45, 47);  // Stepper motor for slot 2
Stepper myStepper3(stepsPerRevolution, 34, 36, 35, 37);  // Stepper motor for slot 3


// Data structure describing a single medicine's schedule and metadata
struct Medicine {

  char medicineName[16];  // Medicine name (15 chars + '\0')

  byte slot;  // 1, 2 or 3

  byte dosesPerDay;  // Number of times per day (1-5)

  byte hour[5];    // Hours for each dose
  byte minute[5];  // Minutes for each dose

  bool days[7];  // Sunday, Monday, Tuesday, Wednesday,
                 // Thursday, Friday, Saturday

  bool enabled;  // Medicine active or not
};

Medicine medicines[3];  // Holds the schedule/config for each of the 3 dispenser slots (index 0-2 = slot 1-3)

//Indroduction function
// Displays a welcome message on the LCD and plays a startup sound.
void introduction() {
  lcd.setCursor(0, 0);
  lcd.print(F("Medicine"));
  lcd.setCursor(0, 1);
  lcd.print(F("Dispenser Ready"));
  player.play(4);   // Play startup/ready audio track #4
}

// Reads the current time from the RTC and refreshes the LCD display
// (date/day on row 2, time on row 1), but only once per second to avoid
// unnecessary I2C traffic/flicker.
void CheckTime() {

  const char* daysOfWeek[] = { "Sun", "Mon", "Tue", "Wed", "Thur", "Fri", "Sat" };
  DateTime now = rtc.now();          // Get current date/time from RTC
  if (millis() - old_time > 1000) {  // Only update the display once per second
    // Line 2: Date
    lcd.setCursor(0, 1);
    lcd.print(now.day());
    lcd.print('/');

    if (now.month() < 10) lcd.print('0');  // Zero-pad single digit months
    lcd.print(now.month());
    lcd.print('/');

    lcd.print(now.year());
    lcd.print("  ");
    lcd.print(daysOfWeek[now.dayOfTheWeek()]);  // Print abbreviated day name

    // Line 1: Time
    lcd.setCursor(0, 0);
    lcd.print("TIME: ");

    if (now.hour() < 10) lcd.print('0');   // Zero-pad single digit hours
    lcd.print(now.hour());
    lcd.print(':');

    if (now.minute() < 10) lcd.print('0');  // Zero-pad single digit minutes
    lcd.print(now.minute());
    lcd.print(':');

    if (now.second() < 10) lcd.print('0');  // Zero-pad single digit seconds
    lcd.print(now.second());
    old_time = millis();  // Remember when we last refreshed the display
  }
}

// Dispenses medicine for whichever slots are flagged true in Dispenser_slot[],
// shows each medicine's name on the LCD, then prompts the user to take their
// medicine and waits (blocking) until the IR sensor detects pickup, repeating
// the audio reminder every `reminderInterval` ms while waiting.
void Dispense(bool Dispenser_slot[]) {
  // Debug: print which slots are being dispensed this round
  for (int s = 0; s < 3; s++) {
    Serial.print("Slot");
    Serial.print(s);
    Serial.print(":");
    Serial.println(Dispenser_slot[s]);
  }
  // Slot 1: show medicine name if flagged for dispensing
  if (Dispenser_slot[0]) {
    lcd.clear();
    lcd.setCursor(0, 0);
    lcd.print(medicines[0].medicineName);
    delay(4000);
  }
  // Slot 2: show medicine name if flagged for dispensing
  if (Dispenser_slot[1]) {
    lcd.clear();
    lcd.setCursor(0, 0);
    lcd.print(medicines[1].medicineName);
    delay(4000);
  }
  // Slot 3: show medicine name if flagged for dispensing
  if (Dispenser_slot[2]) {
    lcd.clear();
    lcd.setCursor(0, 0);
    lcd.print(medicines[2].medicineName);
    delay(4000);
  }
  // Turn each selected carousel once before asking the user to collect it.
  // The original draft configured these motors but never drove them.
  if (Dispenser_slot[0]) myStepper1.step(stepsPerRevolution);
  if (Dispenser_slot[1]) myStepper2.step(stepsPerRevolution);
  if (Dispenser_slot[2]) myStepper3.step(stepsPerRevolution);
    // Prompt the user to take their medicine
    lcd.clear();
    lcd.setCursor(0, 0);
    lcd.print("Please Take Your");
    lcd.setCursor(3, 1);
    lcd.print("Medicines");
  player.play(1);              // Play "take your medicine" audio track #1
  lastReminder = millis();     // Start the reminder repeat timer

  // Wait here until the IR sensor goes LOW (medicine picked up),
  // re-playing the reminder sound periodically while waiting.
  while (digitalRead(IR) == HIGH) {

    if (millis() - lastReminder >= reminderInterval) {
      player.play(1);
      lastReminder = millis();
    }
  }

  // Medicine picked up
  lcd.clear();
  lcd.setCursor(3, 1);
  lcd.print("Thank You");
  delay(4000);
}

// Send exactly one JSON line to the ESP. Never send diagnostic text on Serial3.
void SendEspJson(JsonDocument& doc) {
  serializeJson(doc, Serial3);
  Serial3.println();
}

void SendResponse(int id, bool ok, const char* error = nullptr) {
  JsonDocument doc;
  doc["type"] = "resp";
  doc["id"] = id;
  doc["ok"] = ok;
  if (error != nullptr) doc["error"] = error;
  SendEspJson(doc);
}

void SendTestResponse(int id, bool pass, const char* detail) {
  JsonDocument doc;
  doc["type"] = "resp";
  doc["id"] = id;
  doc["ok"] = true;
  JsonObject data = doc["data"].to<JsonObject>();
  data["pass"] = pass;
  data["detail"] = detail;
  SendEspJson(doc);
}

void SendDispenseComplete(bool slots[], bool detected) {
  for (byte i = 0; i < 3; i++) {
    if (!slots[i]) continue;
    JsonDocument doc;
    doc["type"] = "evt";
    doc["name"] = "dispense_complete";
    JsonObject data = doc["data"].to<JsonObject>();
    data["slot"] = i + 1;
    data["detected"] = detected;
    SendEspJson(doc);
  }
}

DateTime EpochToDateTime(uint32_t epoch) {
  return DateTime(epoch);
}

void HandleEspCommand(const String& line) {
  JsonDocument request;
  if (deserializeJson(request, line)) return;
  if (request["type"].as<String>() != "cmd" || !request["id"].is<int>() || !request["op"].is<const char*>()) return;

  const int id = request["id"].as<int>();
  const String op = request["op"].as<String>();

  if (op == "ping") {
    SendResponse(id, true);
  } else if (op == "get_capabilities") {
    JsonDocument response;
    response["type"] = "resp";
    response["id"] = id;
    response["ok"] = true;
    JsonObject data = response["data"].to<JsonObject>();
    data["rtc"] = true;
    data["speaker"] = true;
    data["display"] = true;
    data["ir"] = true;
    JsonArray steppers = data["steppers"].to<JsonArray>();
    steppers.add(true); steppers.add(true); steppers.add(true);
    SendEspJson(response);
  } else if (op == "get_time") {
    JsonDocument response;
    response["type"] = "resp";
    response["id"] = id;
    response["ok"] = true;
    response["data"]["time"] = rtc.now().unixtime();
    SendEspJson(response);
  } else if (op == "set_time") {
    if (!request["time"].is<uint32_t>()) { SendResponse(id, false, "time required"); return; }
    rtc.adjust(EpochToDateTime(request["time"].as<uint32_t>()));
    SendResponse(id, true);
  } else if (op == "lcd") {
    if (!request["line1"].is<const char*>() || !request["line2"].is<const char*>()) { SendResponse(id, false, "line1 and line2 required"); return; }
    lcd.clear();
    lcd.setCursor(0, 0); lcd.print(request["line1"].as<const char*>());
    lcd.setCursor(0, 1); lcd.print(request["line2"].as<const char*>());
    SendResponse(id, true);
  } else if (op == "play_sound") {
    player.play(1);
    SendResponse(id, true);
  } else if (op == "get_status") {
    JsonDocument response;
    response["type"] = "resp";
    response["id"] = id;
    response["ok"] = true;
    response["data"]["state"] = "ready";
    response["data"]["last_dispense"] = lastDispenseHour < 0 ? 0 : rtc.now().unixtime();
    SendEspJson(response);
  } else if (op == "test") {
    String component = request["component"] | "";
    int slot = request["slot"] | 0;
    if (component == "rtc") SendTestResponse(id, rtc.now().year() >= 2000, "RTC responding");
    else if (component == "ir") SendTestResponse(id, true, digitalRead(IR) == LOW ? "IR detected" : "IR ready");
    else if (component == "speaker") { player.play(1); SendTestResponse(id, true, "Sound started"); }
    else if (component == "display") { lcd.clear(); lcd.print("Display test"); SendTestResponse(id, true, "Display updated"); }
    else if (component == "stepper" && slot >= 1 && slot <= 3) SendTestResponse(id, true, "Stepper configured");
    else SendTestResponse(id, false, "Unsupported component");
  } else if (op == "dispense") {
    int slot = request["slot"] | 0;
    if (slot < 1 || slot > 3) { SendResponse(id, false, "slot must be 1-3"); return; }
    bool selected[3] = { false, false, false };
    selected[slot - 1] = true;
    JsonDocument response;
    response["type"] = "resp";
    response["id"] = id;
    response["ok"] = true;
    response["data"]["status"] = "started";
    SendEspJson(response);
    Dispense(selected);
    SendDispenseComplete(selected, digitalRead(IR) == LOW);
  } else {
    SendResponse(id, false, "unsupported operation");
  }
}

// Checks the current time against every enabled medicine's schedule and
// triggers dispensing for any medicine whose dose time matches "now".
// Ensures dispensing only happens once per matching minute.
void AlertMedicine() {
  DateTime now = rtc.now();

  // Already dispensed during this minute
  if (now.hour() == lastDispenseHour &&
      now.minute() == lastDispenseMinute) {
    return;
  }

  bool Dispenser_slot[3] = {false, false, false};  // Which slots need to dispense this round
  bool dispenseNow = false;                        // Whether any slot matched the current time

  for (int i = 0; i < 3; i++) {

    if (!medicines[i].enabled)          // Skip disabled/empty slots
      continue;

    if (!medicines[i].days[now.dayOfTheWeek()])  // Skip if not scheduled for today
      continue;

    // Check each configured dose time for this medicine
    for (int j = 0; j < medicines[i].dosesPerDay; j++) {

      if (medicines[i].hour[j] == now.hour() &&
          medicines[i].minute[j] == now.minute()) {

        Serial.print(medicines[i].medicineName);
        Serial.println(" is dispensed");

        Dispenser_slot[i] = true;  // Mark this slot for dispensing
        dispenseNow = true;
        break;                     // No need to check remaining doses for this medicine
      }
    }
  }

  if (dispenseNow) {
    Dispense(Dispenser_slot);  // Perform the actual dispensing/pickup sequence

    // Remember this minute so we don't dispense again until the next match
    lastDispenseHour = now.hour();
    lastDispenseMinute = now.minute();
  }
}

// Prints the full configuration of all 3 medicine slots to Serial,
// for debugging/verification purposes.
void DisplayMedicines() {
  const char* days[] = {
    "Sun", "Mon", "Tue", "Wed", "Thu", "Fri", "Sat"
  };

  for (int i = 0; i < 3; i++) {
    Serial.println("======================");
    Serial.print("Slot: ");
    Serial.println(i + 1);

    Serial.print("Medicine: ");
    Serial.println(medicines[i].medicineName);

    Serial.print("Doses: ");
    Serial.println(medicines[i].dosesPerDay);

    Serial.print("Times: ");

    // Print each configured dose time (HH:MM)
    for (int j = 0; j < medicines[i].dosesPerDay; j++) {
      Serial.print(medicines[i].hour[j]);
      Serial.print(":");

      if (medicines[i].minute[j] < 10)
        Serial.print('0');  // Zero-pad single digit minutes

      Serial.print(medicines[i].minute[j]);
      Serial.print("  ");
    }

    Serial.println();

    Serial.print("Days: ");

    // Print which days of the week this medicine is scheduled
    for (int j = 0; j < 7; j++) {
      if (medicines[i].days[j]) {
        Serial.print(days[j]);
        Serial.print(" ");
      }
    }

    Serial.println();

    Serial.print("Enabled: ");
    Serial.println(medicines[i].enabled);
  }
}

// Parses a comma-separated medicine definition string (received over Serial)
// and stores it both in RAM (medicines[]) and in EEPROM for persistence.
//
// Expected format (comma-separated):
//   name,slot,dosesPerDay,HH:MM,HH:MM,HH:MM,HH:MM,HH:MM,day0,day1,...,day6,enabled
//   - Unused dose slots are marked "99:99"
//   - Days not scheduled are marked "X"; scheduled days are given as their index (0-6)
void NewMedicine(char* data) {
  Medicine med;

  char* token;

  //---------------- Medicine Name ----------------
  token = strtok(data, ",");
  strcpy(med.medicineName, token);

  //---------------- Slot ----------------
  token = strtok(NULL, ",");
  med.slot = atoi(token);

  //---------------- Doses Per Day ----------------
  token = strtok(NULL, ",");
  med.dosesPerDay = atoi(token);

  //---------------- Five Times ----------------
  // Always parse exactly 5 dose-time fields (unused ones are "99:99" placeholders)
  for (int i = 0; i < 5; i++) {
    token = strtok(NULL, ",");

    if (strcmp(token, "99:99") == 0) {
      med.hour[i] = 255;    // 255 marks an unused/inactive dose slot
      med.minute[i] = 255;
    } else {
      sscanf(token, "%hhu:%hhu",
             &med.hour[i],
             &med.minute[i]);
    }
  }

  //---------------- Clear Days ----------------
  for (int i = 0; i < 7; i++)
    med.days[i] = false;

  //---------------- Seven Day Fields ----------------
  // Each field is either "X" (not scheduled) or a day index 0-6 (scheduled)
  for (int i = 0; i < 7; i++) {
    token = strtok(NULL, ",");

    if (strcmp(token, "X") != 0) {
      byte day = atoi(token);

      if (day < 7)
        med.days[day] = true;
    }
  }

  //---------------- Enabled ----------------
  token = strtok(NULL, ",");

  med.enabled = atoi(token);

  //---------------- Save in RAM ----------------
  medicines[med.slot - 1] = med;  // Slots are 1-indexed in the protocol, 0-indexed in the array

  //---------------- Save in EEPROM ----------------
  int address = (med.slot - 1) * sizeof(Medicine);  // Each slot gets its own fixed-size EEPROM block

  EEPROM.put(address, medicines[med.slot - 1]);

  Serial.println("Medicine Saved Successfully");
  lcd.clear();
  lcd.setCursor(0, 0);
  lcd.print("Data Stored");
}

// Reports (over Serial) which slots currently have no medicine configured (disabled).
void Empty_Slot() {
  Serial.println('\n');
  for (int i = 0; i < 3; i++) {
    if (medicines[i].enabled == 0) {
      Serial.print("Slot:");
      Serial.print(i + 1);
      Serial.println(" is empty.");
    }
  }
}

// Shows a "Debugging" message on the LCD, then dumps all medicine
// configurations to Serial via DisplayMedicines().
void Debug_Machine() {
  lcd.clear();
  lcd.setCursor(0, 1);
  lcd.print("Debugging......");
  delay(2000);
  DisplayMedicines();
}

// Reads newline-delimited JSON commands from the ESP8266 on Serial3.
void Serial_ESP() {
  while (Serial3.available()) {
    char c = (char)Serial3.read();
    if (c == '\n') {
      if (espRxBuffer.length() > 0) HandleEspCommand(espRxBuffer);
      espRxBuffer = "";
    } else if (c != '\r') {
      if (espRxBuffer.length() < 512) espRxBuffer += c;
      else espRxBuffer = "";  // Drop an overlong malformed frame.
    }
  }
}

// Arduino setup routine: initializes all peripherals (steppers, I2C bus,
// Serial ports, RTC, IR sensor, LCD, DFPlayer) and restores saved medicine
// schedules from EEPROM before showing the ready screen.
void setup() {
  myStepper1.setSpeed(10);  // RPM
  myStepper2.setSpeed(10);  // RPM
  myStepper3.setSpeed(10);  // RPM

  Wire.begin();  // Uses Mega pins 20 and 21
  Serial.begin(9600);   // Main Serial (USB / debug / command interface)
  Serial2.begin(9600);  // Used by DFPlayer Mini
  Serial3.begin(9600);  // ESP8266

  // Restore all 3 medicine schedules from EEPROM into RAM
  for (int i = 0; i < 3; i++) {
    EEPROM.get(i * sizeof(Medicine), medicines[i]);
  }

  // Halt if the RTC module isn't detected - nothing else can work without it
  if (!rtc.begin()) {
    Serial.println("RTC not found");
    while (1)
      ;
  }

  // Uncomment once to set the time
  // rtc.adjust(DateTime(F(__DATE__), F(__TIME__)));

  pinMode(IR, INPUT);   // IR pickup sensor

  lcd.init();         // Initialize LCD
  lcd.backlight();  // Turn on backlight


  // DFPlayer --------------------------------------------------------------
  if (player.begin(Serial2)) {
    player.volume(25);   // Set default playback volume (0-30)
  } else {
    Serial.println(F("DFPlayer NOT detected!"));
  }
  //Machine Start
  introduction();  // Show ready screen / play startup sound
  delay(4000);
}

// Main loop: continuously refresh the clock display, check whether any
// medicine is due, and listen for incoming Serial commands.
void loop() {
  CheckTime();
  AlertMedicine();
  Serial_ESP();
}

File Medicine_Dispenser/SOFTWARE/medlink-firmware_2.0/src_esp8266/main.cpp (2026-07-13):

#include <Arduino.h>
#include <SoftwareSerial.h>
#include <ArduinoJson.h>
#include <protocol.h>
#include "WiFiManager.h"
#include "TimeSource.h"
#include "StorageManager.h"
#include "SerialBridge.h"
#include "ApiManager.h"
#include "Scheduler.h"

// SoftwareSerial RX = D5, TX = D6 for communication
SoftwareSerial swSerial(D5, D6);

void setup() {
  // Initialize Hardware Serial (USB) for debugging
  Serial.begin(115200);
  delay(500);
  Serial.println("ESP8266 Medlink Node Started.");

  // Initialize Software Serial at 9600 baud
  swSerial.begin(9600);

  // Initialize all subsystems
  StorageManager::begin();
  SerialBridge::begin(swSerial);
  WiFiManager::begin();
  TimeSource::begin();
  ApiManager::begin();
  Scheduler::begin();
}

void loop() {
  // Update state machines and poll serial link
  WiFiManager::update();
  TimeSource::update();
  SerialBridge::poll();
  ApiManager::update();
  Scheduler::update();

}

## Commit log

2026-06-16 spool 3d
    [3D SPOOL.f3d, AIR BOTTLE.stl, bottle cap.stl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]
2026-06-17 3D SPOOL
    [3D SPOOL.f3d]
2026-06-17 pcb design
    [ELECTRONICS.kicad_sch]
2026-06-18 med box layout
    [ELECTRONICS.kicad_pcb]
2026-06-28 base model
    [Dispenser base updates.f3d]
2026-06-29 base mdf and slope
    [base.dxf]
2026-06-29 base stl
    [Dispenser base.f3d, Dispenser base.stl]
2026-07-03 feat: add module registry framework
2026-07-03 feat: implement REST API framework
2026-07-03 almost hogaya hai bas bugs bache hai
    [ApiManager.cpp]
2026-07-06 Code pcb update
2026-08-04 clean up
    [ELECTRONICS.kicad_pcb, ELECTRONICS.kicad_sch]
